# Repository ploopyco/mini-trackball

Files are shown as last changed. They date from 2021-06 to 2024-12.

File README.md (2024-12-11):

# The Ploopy Mini Trackball

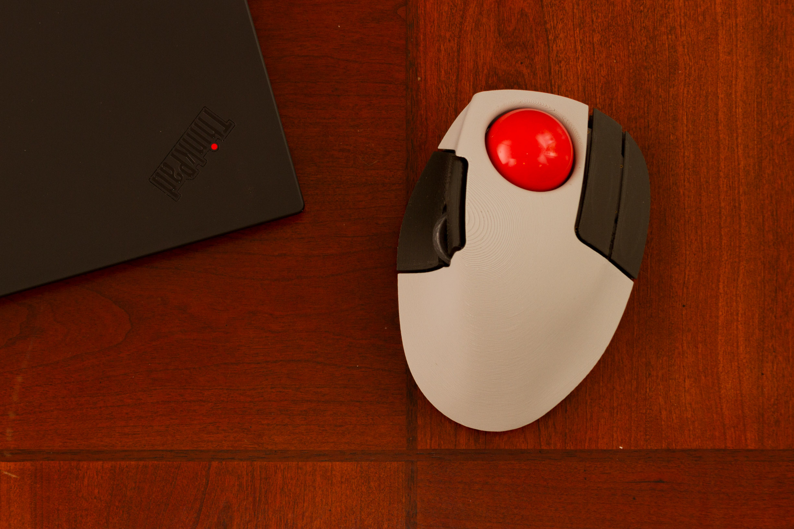
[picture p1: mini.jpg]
The Ploopy Mini Trackball


By some stroke of luck, you've made your way here. The Ploopy Mini Trackball. Your life will never be the same.

This repository contains all of the design and production files necessary to make a Ploopy Mini Trackball. We've also included some kick-ass documentation in the Wiki on how to get it made, assemble it, and program it.

What are you waiting for? Your new life awaits.

## QMK?!

Kits bought from the [Ploopy store](https://ploopy.co/product-category/trackball/mini/) come with QMK preloaded. Check out the Wiki for instructions on how to load new firmware onto your device. (It's super easy!)

The firmware hex file that ships with all Minis is included in this repository as well, as `ploopyco_trackball_mini_rev1_002_default.hex`.

## Under what license is this released?

As per QMK's licensing requirements, the firmware for the Ploopy Mini Trackball is released under GPLv3. Hardware design files, including electronics and mechanical files, are released under OHL CERN v2-S. Check the `LICENSE` file for full license text.

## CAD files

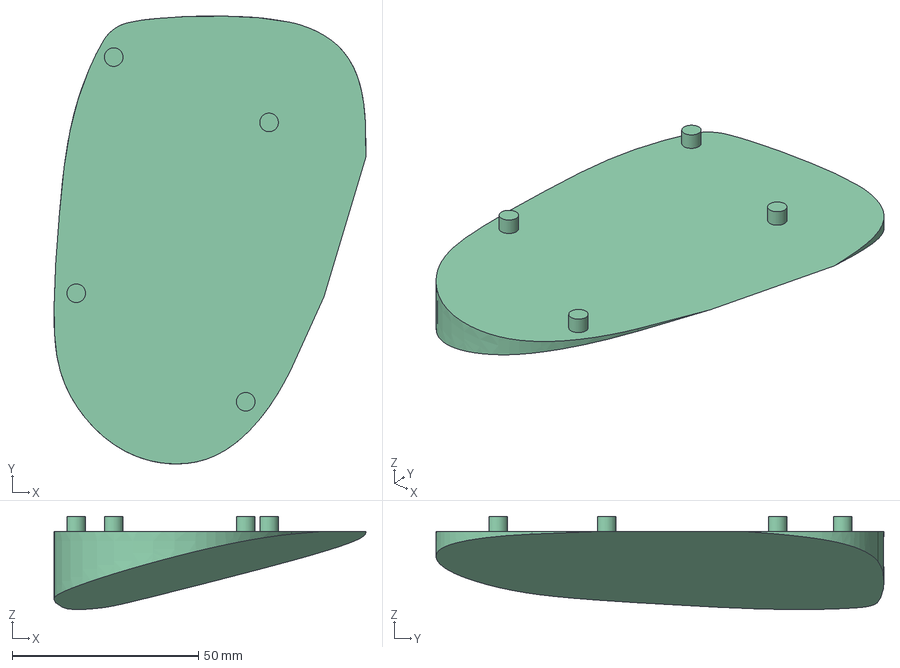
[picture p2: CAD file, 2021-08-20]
hardware/mechanicals/step/wedge.step
83.7 x 120.3 x 25.0 mm

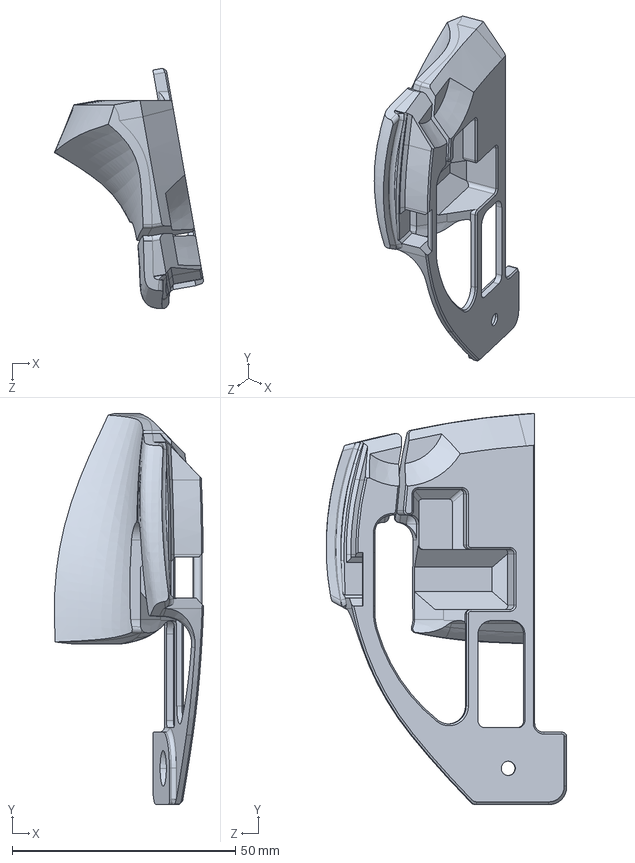
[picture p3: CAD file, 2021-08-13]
hardware/mechanicals/step/PrimaryButtons.STEP
33.5 x 87.6 x 53.9 mm

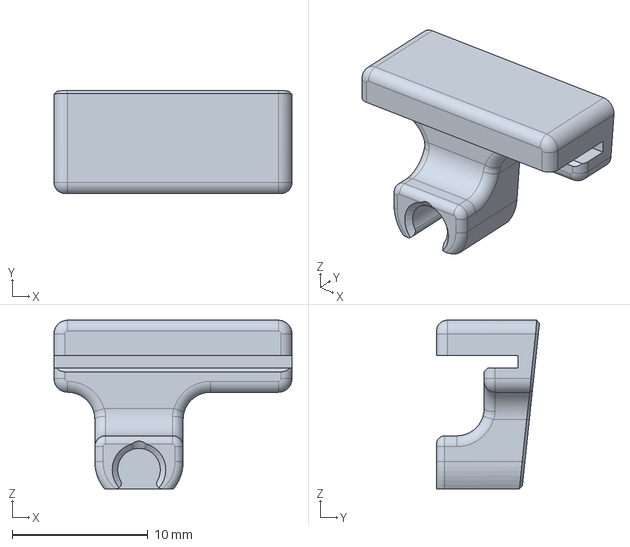
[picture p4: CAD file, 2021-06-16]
hardware/mechanicals/step/PCBScrollWheelHolder.STEP
17.5 x 7.58 x 12.4 mm

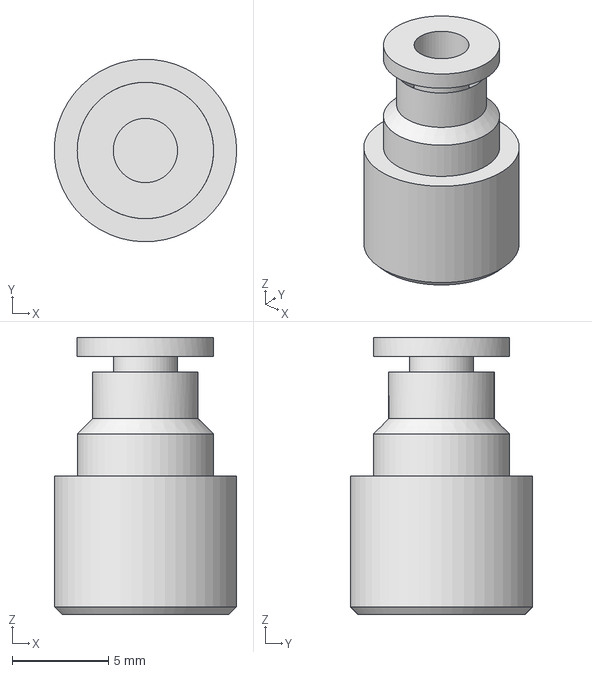
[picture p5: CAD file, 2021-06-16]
hardware/mechanicals/step/ScrollWheelHolder.step
9.49 x 9.50 x 14.4 mm

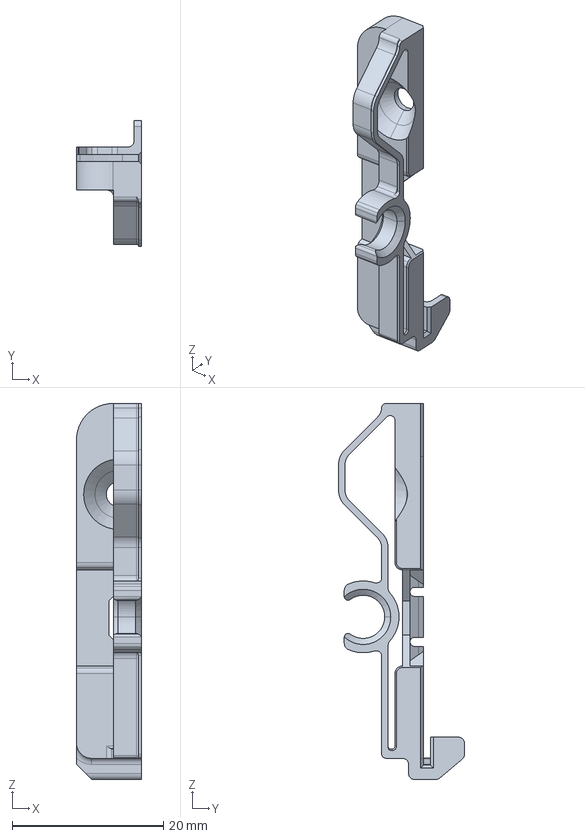
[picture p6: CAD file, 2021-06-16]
hardware/mechanicals/step/ScrollWheelHolderHolder.step
8.60 x 16.7 x 49.7 mm

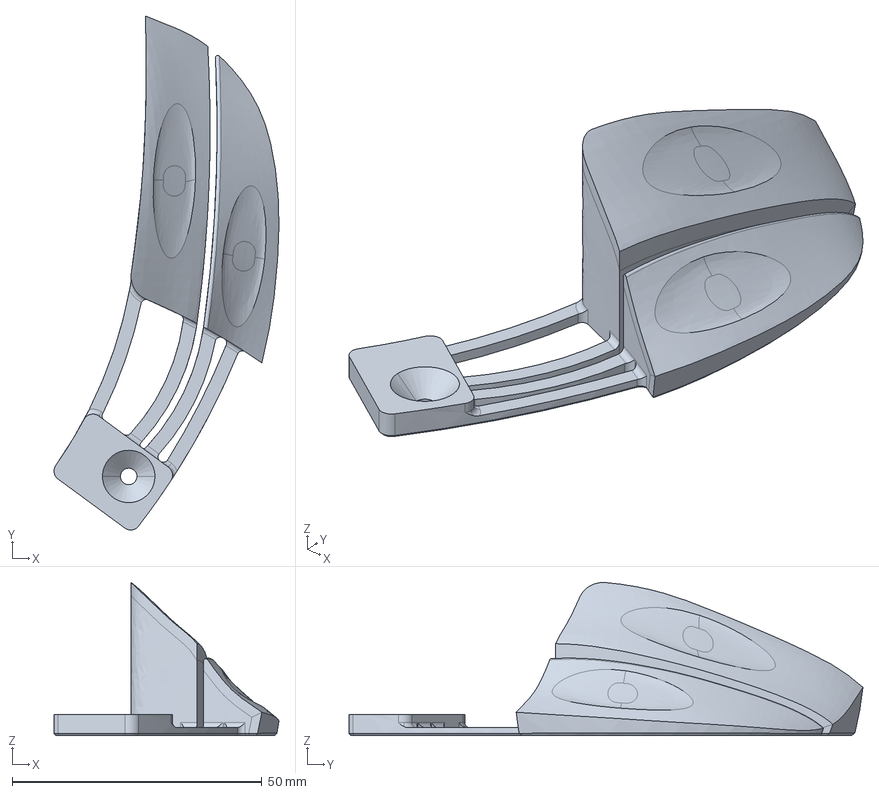
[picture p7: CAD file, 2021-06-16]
hardware/mechanicals/step/SecondaryButtons.STEP
45.1 x 102.9 x 30.7 mm

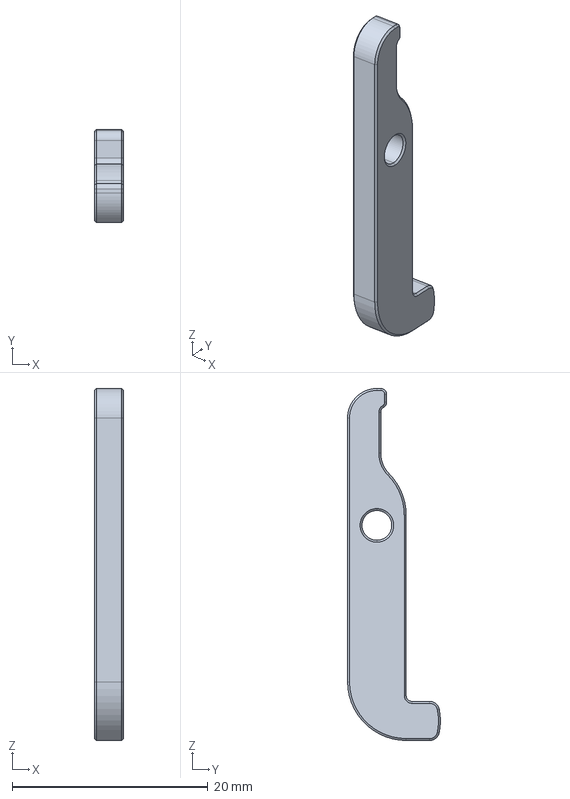
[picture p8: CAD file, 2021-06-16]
hardware/mechanicals/step/ButtonLever.STEP
3.00 x 9.50 x 36.0 mm

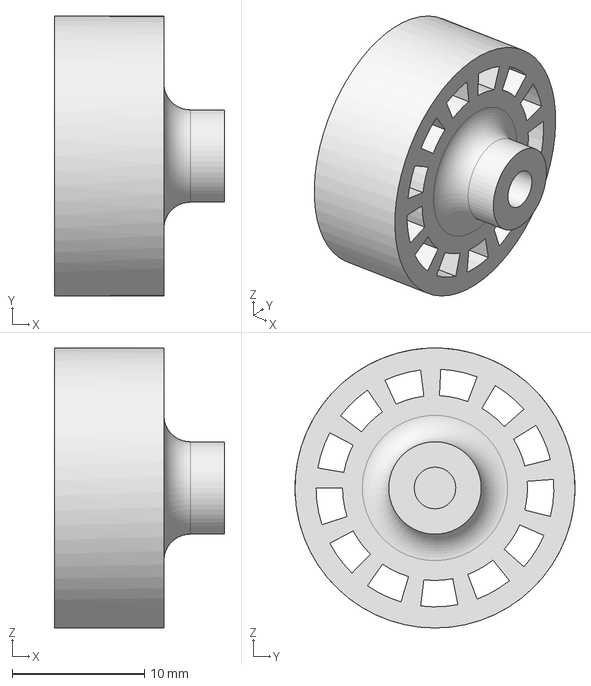
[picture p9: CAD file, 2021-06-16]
hardware/mechanicals/step/ScrollWheel.step
12.9 x 21.2 x 21.2 mm

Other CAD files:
hardware/mechanicals/stl/ButtonLever.STL
hardware/mechanicals/stl/PCBScrollWheelHolder.STL
hardware/mechanicals/stl/PrimaryButtons.STL
hardware/mechanicals/stl/ScrollWheel.stl
hardware/mechanicals/stl/ScrollWheelHolder.stl
hardware/mechanicals/stl/ScrollWheelHolderHolder.STL
hardware/mechanicals/stl/SecondaryButtons.STL
hardware/mechanicals/stl/wedge.stl

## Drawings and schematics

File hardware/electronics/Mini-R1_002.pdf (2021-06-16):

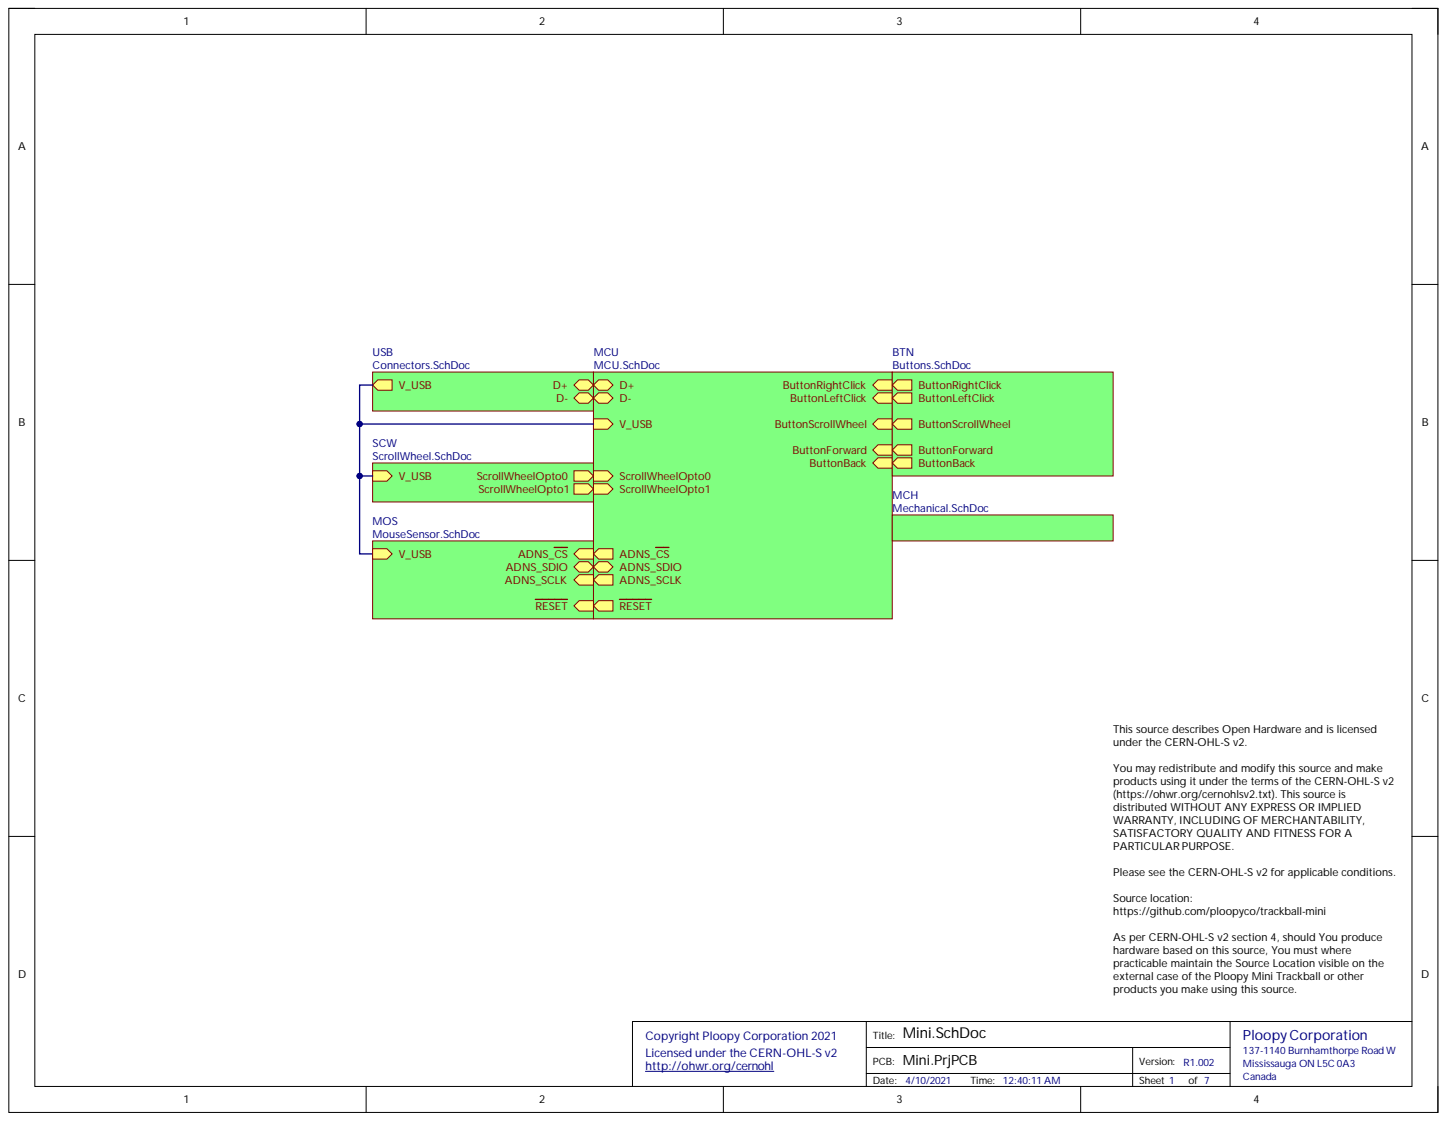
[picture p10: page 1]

V_USB D+ | D+ ButtonRightClick D-ButtonLeftClick V_USB ButtonScrollWheel ButtonForward ButtonBack ScrollWheelOpto0 ScrollWheelOpto1 ADNS_CS ADNS_SDIO ADNS_SCLK RESET | ButtonRightClick ButtonLeftClick ButtonScrollWheel ButtonForward ButtonBack

This source describes Open Hardware and is licensed
under the CERN-OHL-S v2.

You may redistribute and modify this source and make
products using it under the terms of the CERN-OHL-S v2
(https://ohwr.org/cernohlsv2.txt). This source is
distributed WITHOUT ANY EXPRESS OR IMPLIED
WARRANTY, INCLUDING OF MERCHANTABILITY,
SATISFACTORY QUALITY AND FITNESS FOR A
PARTICULAR PURPOSE.

Please see the CERN-OHL-S v2 for applicable conditions.

Source location:
https://github.com/ploopyco/trackball-mini

As per CERN-OHL-S v2 section 4, should You produce
hardware based on this source, You must where
practicable maintain the Source Location visible on the
external case of the Ploopy Mini Trackball or other
products you make using this source.

Copyright Ploopy Corporation 2021
Licensed under the CERN-OHL-S v2
http://ohwr.org/cernohl

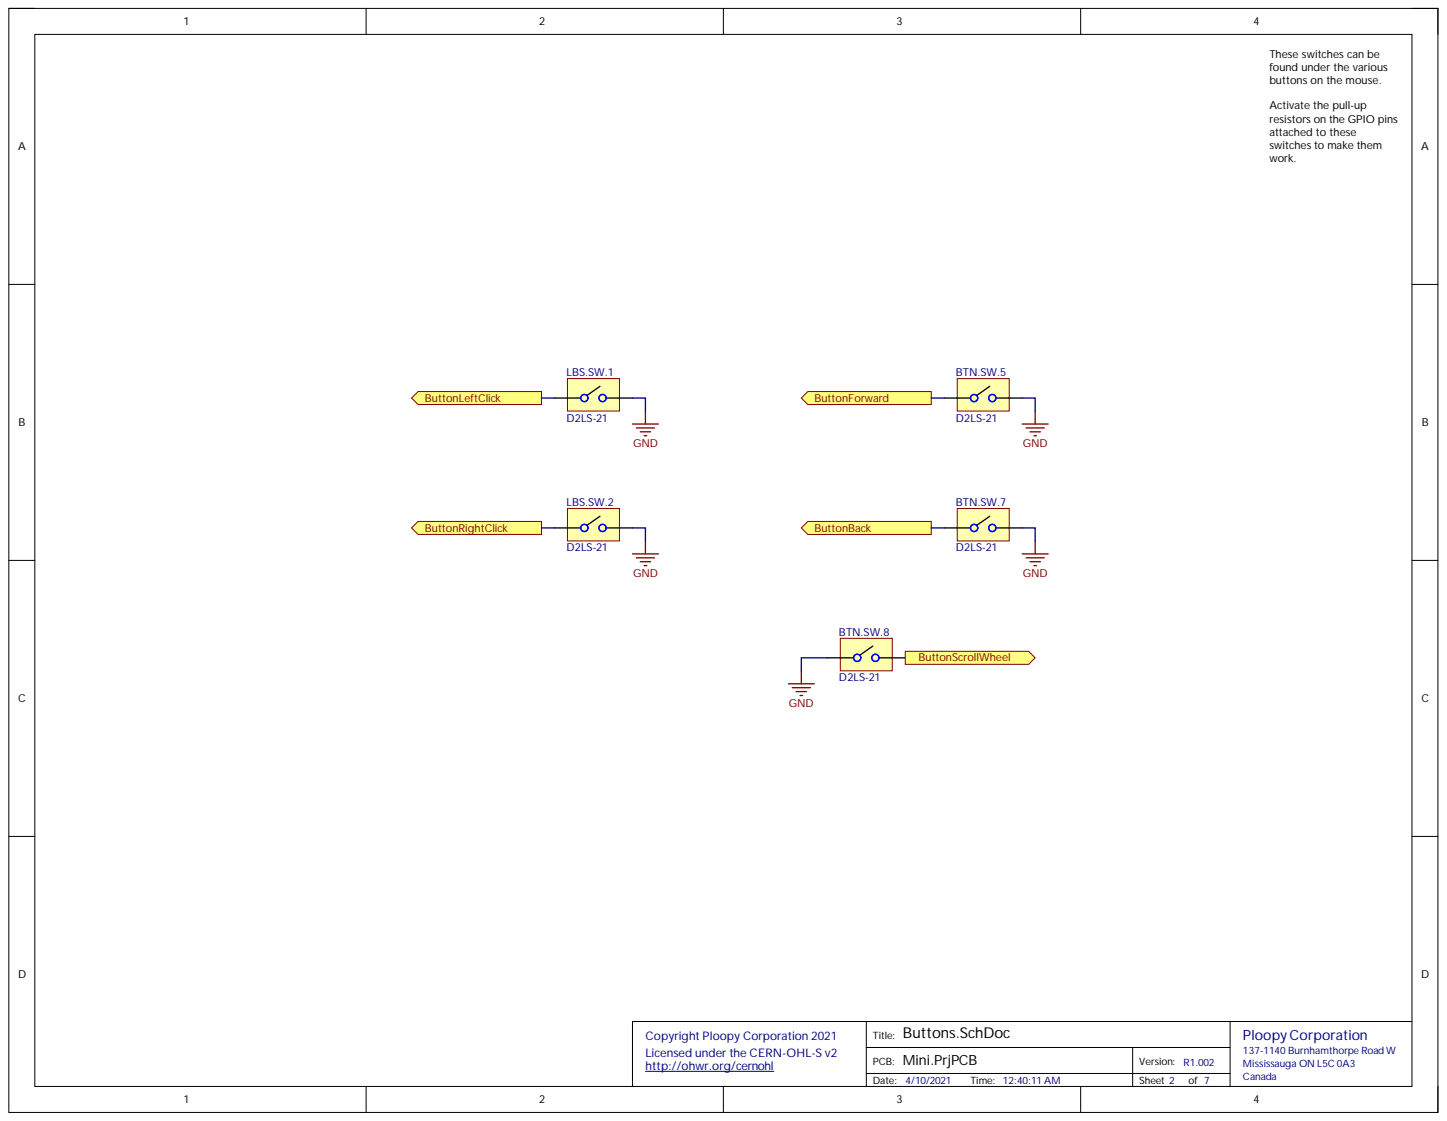
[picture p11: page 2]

These switches can be
found under the various
buttons on the mouse.

Activate the pull-up
resistors on the GPIO pins
attached to these
switches to make them
work.

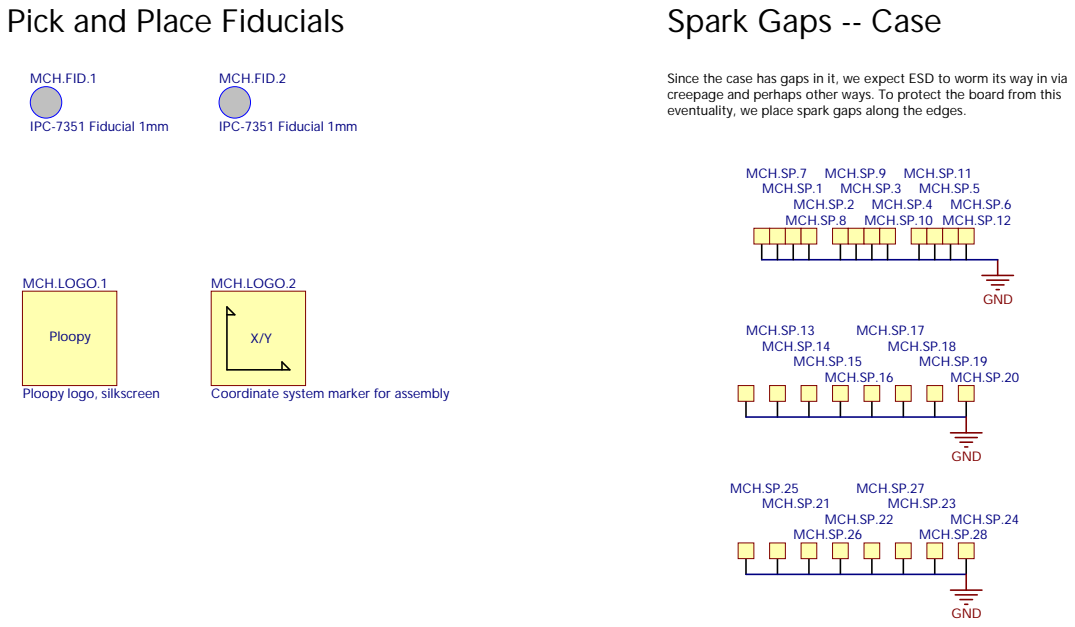
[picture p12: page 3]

Pick and Place Fiducials

Spark Gaps -- Case MCH.SP.7 MCH.SP.1 MCH.SP.8 MCH.SP.2 MCH.SP.9 MCH.SP.3 MCH.SP.10 MCH.SP.4 MCH.SP.1

Since the case has gap
creepage and perhap
eventuality, we place s

s other ways. To protect the board from this
park gap

pect ESD to worm its way in via

Coordinate system marker for assem

Cop
Licensed under the CE
http

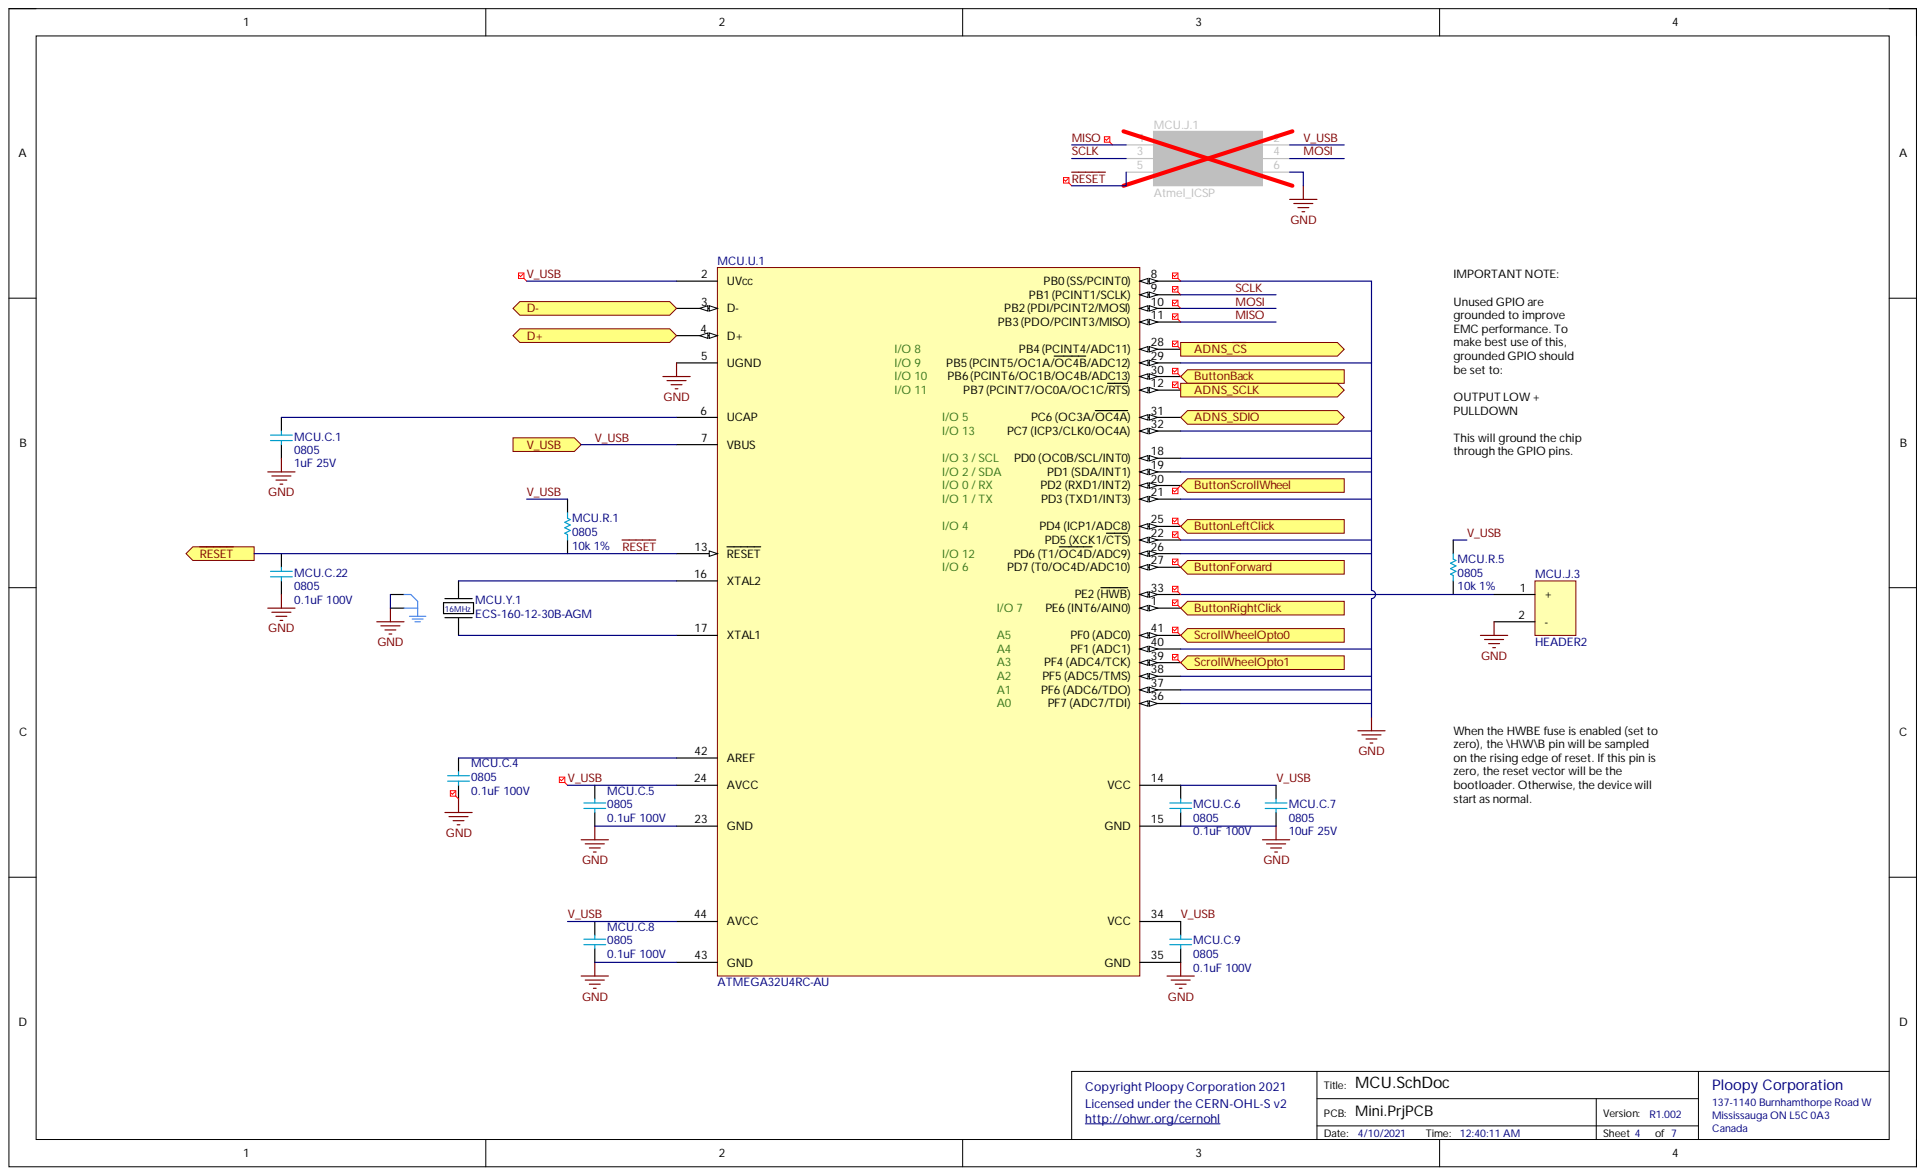
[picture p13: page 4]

Unused GPIO are
grounded to improve
EMC performance. To
make best use of this,
grounded GPIO should
be set to:

This will ground the chip
through the GPIO pins.

When the HWBE fuse is enabled (set to
zero), the \H\W\B pin will be sampled
on the rising edge of reset. If this pin is
zero, the reset vector will be the
bootloader. Otherwise, the device will
start as normal.

Copyright Ploopy Corporation 2021 Licensed under the CERN-OHL-S v2 http://ohwr.org/cernohl | Title: MCU.SchDoc | Ploopy Corporation 137-1140 Burnhamthorpe Road W Mississauga ON L5C 0A3 Canada

PCB: Mini.PrjPCB | Version: R1.002

Date: 4/10/2021 Time: 12:40:11 AM | Sheet 4 of 7

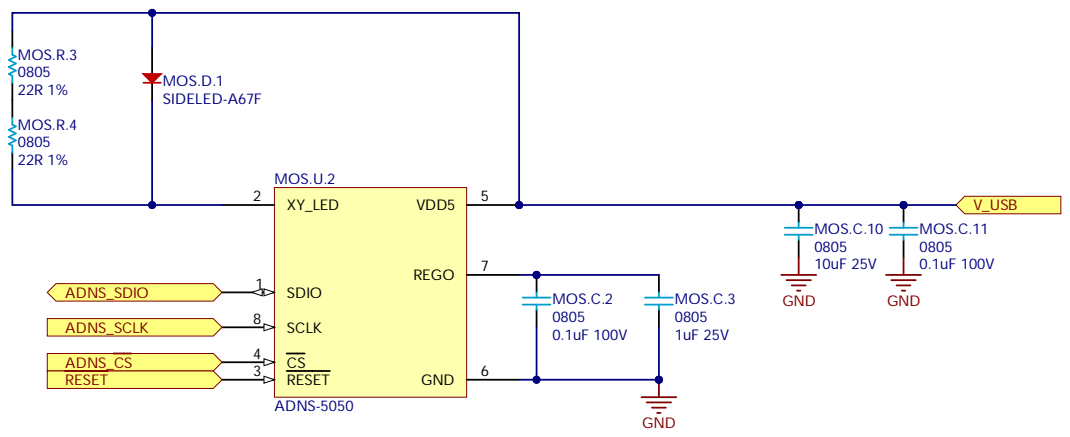
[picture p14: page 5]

Cop
Licensed under the CE
http

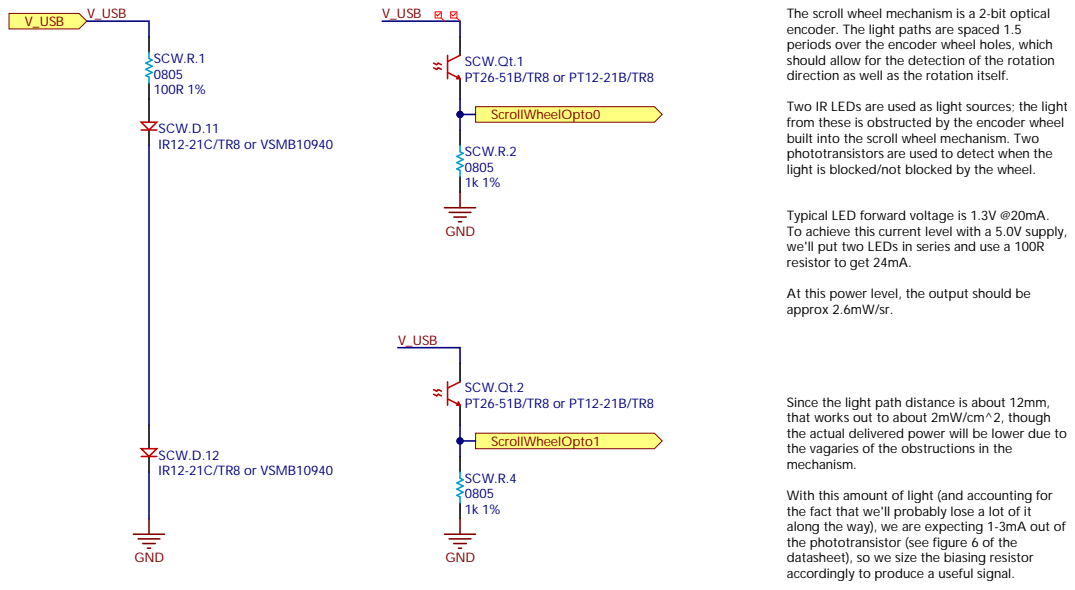
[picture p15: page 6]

The scroll wheel mechanism is a 2-bit optical
encoder. The light paths are spaced 1.5
periods over the encoder wheel holes, which
should allow for the detection of the rotation
direction as well as the rotation itself.

Two IR LEDs are used as light sources; the light
from these is obstructed by the encoder wheel
built into the scroll wheel mechanism. Two
phototransistors are used to detect when the
light is blocked/not blocked by the wheel.

Typical LED forward voltage is 1.3V @20mA.
To achieve this current level with a 5.0V supply,
we'll put two LEDs in series and use a 100R
resistor to get 24mA.

At this power level, the output should be
approx 2.6mW/sr.

Since the light path distance is about 12mm,
that works out to about 2mW/cm^2, though
the actual delivered power will be lower due to
the vagaries of the obstructions in the
mechanism.

With this amount of light (and accounting for
the fact that we'll probably lose a lot of it
along the way), we are expecting 1-3mA out of
the phototransistor (see figure 6 of the
datasheet), so we size the biasing resistor
accordingly to produce a useful signal.

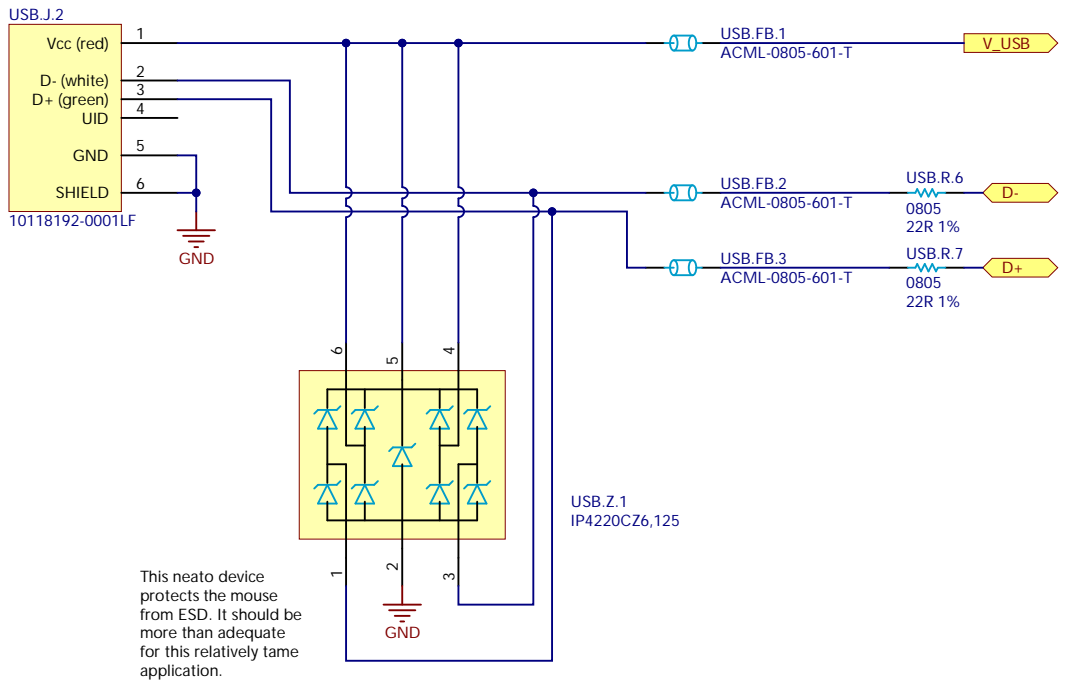
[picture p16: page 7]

This neato device
protects the mouse
from ESD. It should be
more than adequate
for this relatively tame
application.

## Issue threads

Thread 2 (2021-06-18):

Gerber files?

ggppjj, 2021-06-18:
Hello!

Sorry if I'm being dense, I'm a bit new to getting PCBs manufactured, and to be honest wouldn't be bothering if there were a prebuilt PCB-only option on the store. I'm trying to figure out how to get the PCBs made, the instructions and my own general (if lacking) understanding tells me to upload these files to a PCB manufacturer, but I can't seem to find one that recognizes the Altium project files as-is, is there a specific manufacturer that does?

Alternatively, would you be willing to export the Gerber files from Altium? I tried to import the project to CircuitMaker to attempt it myself, but I genuinely cannot figure out how to import the project and I can't possibly afford the full Altium suite for one low-volume order that I was hoping to make.

Thanks, sorry again if there's something I'm just not understanding here.

timmit99, 2021-06-18:
I'll second the "PCB Only Kit" Option. I currently have the parts printing since i want them in my own colors but would love to support the project by purchasing the PCB and switches from the store.

daniel-dsouza, 2021-06-18:
I would also love to see an option for downloading and/or purchasing the Gerber files which I could upload to Advanced Circuits or similar. Having a parts list which I could also import into Digikey would be convenient.

Or perhaps having a completely un-assembled kit with just the PCB and non-3d printed components?

Closed 2024-04-08.

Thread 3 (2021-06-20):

Shop option to buy only mounted PCB.

metrolan, 2021-06-20:
I Want to 3D print one but also support the project buying PCB and electronics.
Can you sell mounted PCB's for people like I?

timmit99, 2021-06-23:
I would love to build one but I want to print it in my colors. A pcb kit would be perfect to help support the project while not wasting the plastic parts in the full kit.

Closed 2024-04-08.

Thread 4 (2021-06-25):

Bearing pins

timmit99, 2021-06-25:
Is there a reason the bearing pins are printed? Could they be the same M3 rod stock used for the switch arm levers and scroll wheel?

ploopyco, 2024-04-08:
Rod stock may also work, but it may not fit snugly the same way the printed pins do.

Closed 2024-04-08.

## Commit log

2020-12-18 added shape test
    [shape-test.stl]
2021-06-16 initial release
    [ButtonLever.STEP, ButtonLever.STL, Buttons.SchDoc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]
2021-08-13 updated primary buttons to include tab to lower occurrences of breakage
    [PrimaryButtons.STEP, PrimaryButtons.STL]
2021-08-18 Add tenting wedge files
    [mini_ploopy_wedge_v1-wedge.step, mini_ploopy_wedge_v2-wedge.step, ploopy_mini_wedge_v1.stl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]
2021-08-18 Remove worse version of tenting wedge
    - Remove inferior wedge from repo
    - Rename the good wedge to remove now redundant version number
    [mini_ploopy_wedge.step, mini_ploopy_wedge_v1-wedge.step, ploopy_mini_wedge.stl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]
2021-08-20 Rename tenting files to be a bit less redundant
    - Specifying the wedge is for the ploopy mini in the mini repo is
    not necessary
    [wedge.step, wedge.stl]
